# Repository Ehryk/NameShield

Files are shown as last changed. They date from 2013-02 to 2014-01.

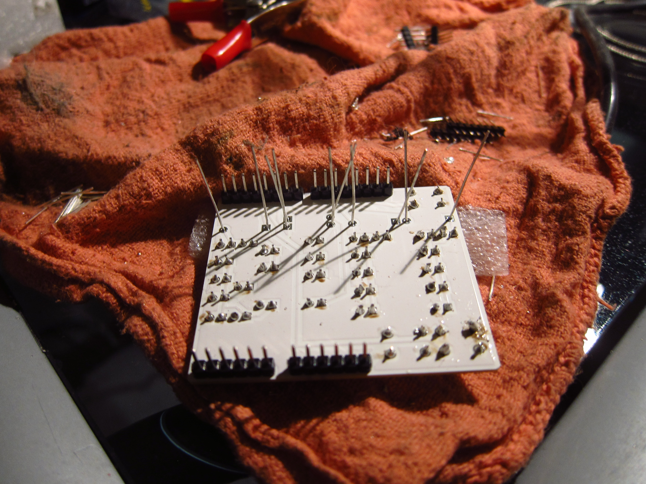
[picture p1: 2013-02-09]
Documentation/Pictures/4 - Soldering Bill.jpg

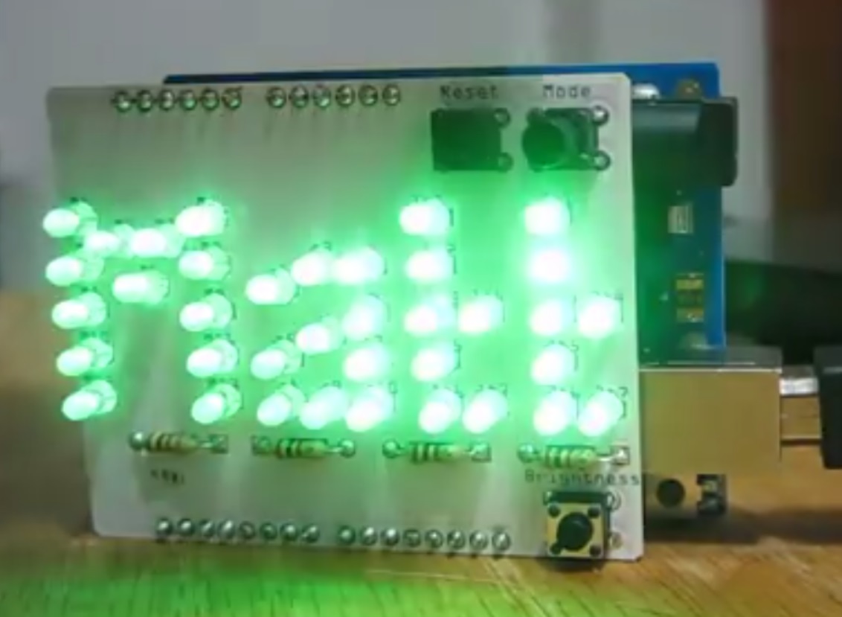
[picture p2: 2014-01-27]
Documentation/Pictures/8 - Matt LEDs On.jpg

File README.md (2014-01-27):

NameShield
==========

This is an Arduino based project that flashes text or a name on a shield, with various modes and brightnesses selectable via tact switches. It uses PWM output pins (six on an Arduino Uno/Duemilanove) to control brightness levels when necessary. I designed the circuit boards in Fritzing, then ordered them from their fabrication plant, and soldered the LEDs on.

Eric LEDs On

See the assembled ones on YouTube in various modes:
 - Eric [View on YouTube](https://www.youtube.com/watch?v=vqsRCEPevEo)
 - Bill [View on YouTube](https://www.youtube.com/watch?v=BqNwpaYB2X8)
 - Matt [View on YouTube](https://www.youtube.com/watch?v=KLYUQCO8-6A)

**Code**

These are the code files that drive the Name shields with LEDs.

Current Modes (you can easily write your own, be sure to customize them in the Modes.ino file):

 1. All On
 1. Blink All (at once)
 1. Blink All (at once) - Fast
 1. Sequential
 1. Sequential - Fast
 1. Wave
 1. Wave - Fast
 1. Blink Dot of i (if applicable)
 1. Blink First Letter
 1. Blink Second Letter
 1. Blink Third Letter
 1. Blink Fourth Letter (if applicable)
 1. Fade All
 1. Fade All - Fast
 1. Fade All - Slow
 1. All Bright
 1. All Off

**Schematics**

These are Fritzing .fzz files that define PCB schematics that can be ordered as Arduino shields. Visit [Fritzing](http://www.fritzing.org) for more information.

**Implementations**

Currently, I have built `Eric`, `Matt`, `Bill`, and `RDI`. If you'd like me to make one for you, [Email Me](mailto:ehryk42@gmail.com) or download fritzing and the Arduino IDE and build your own!

Here are some of the other variants:

Bill LEDs On
Matt LEDs On
RDI LEDs On

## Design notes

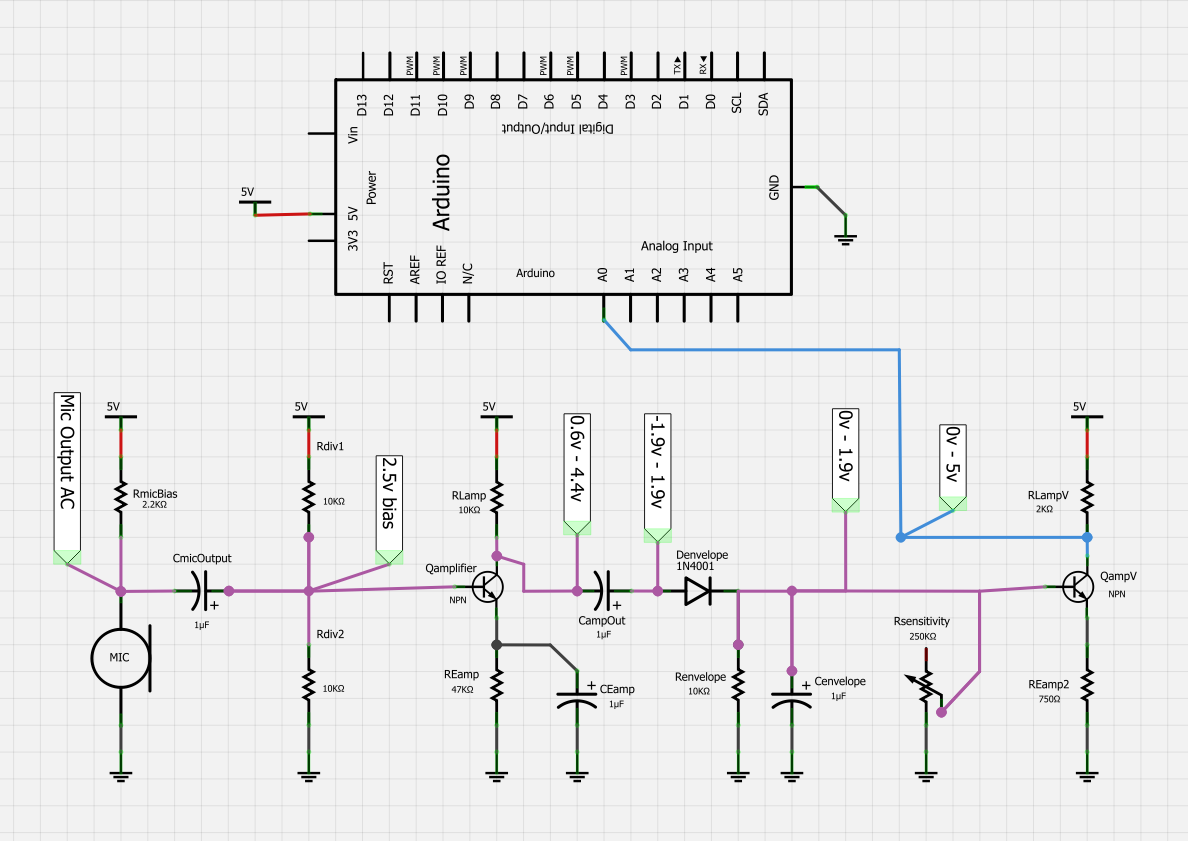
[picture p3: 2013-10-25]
Documentation/Pictures/Circuit/Electret Microphone - Complex.png

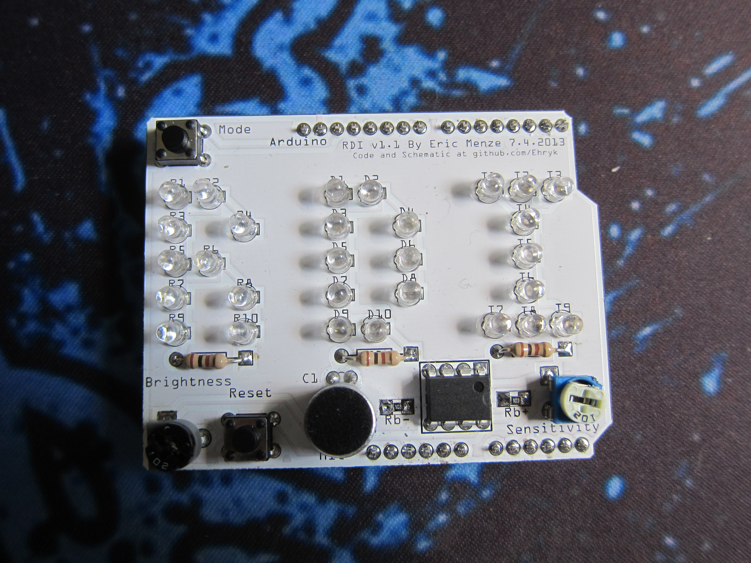
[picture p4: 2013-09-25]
Documentation/Pictures/RDI 3 - Populated Front.jpg

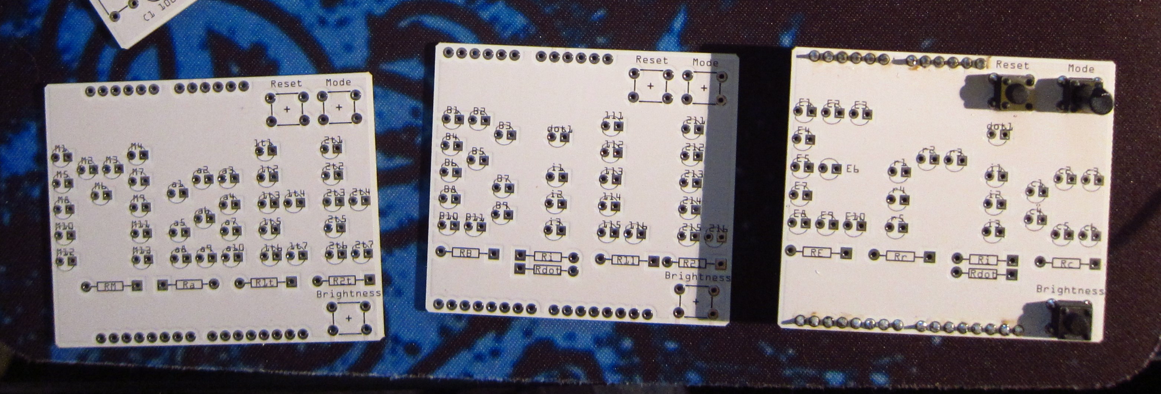
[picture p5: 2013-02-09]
Documentation/Pictures/2 - Matt, Bill, Eric PCBs.jpg

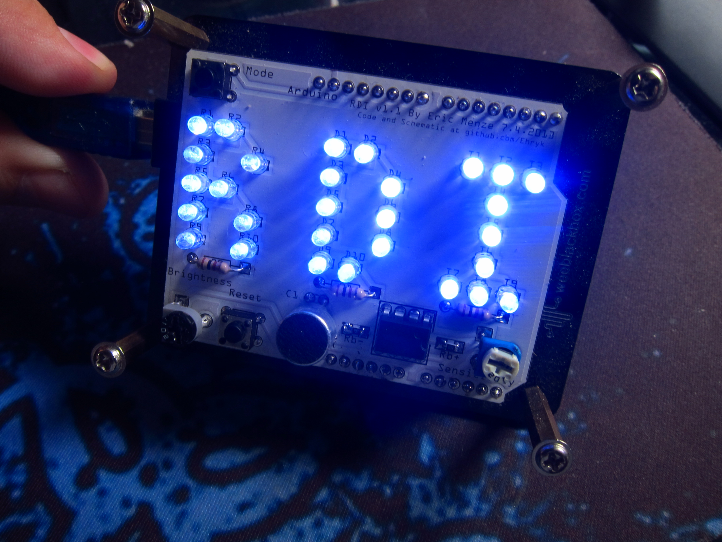
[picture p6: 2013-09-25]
Documentation/Pictures/RDI 6 - Angled.jpg

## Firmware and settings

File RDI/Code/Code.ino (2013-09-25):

/*
NameShield LED Driver
Eric Menze
http://www.github.com/Ehryk
*/

//Configure Letters
/* RDI */
int letters = 3;
char* letter[3] = {"R", "D", "I"};
int pinCount[3] = {1, 1, 1};
int letterPin[3][1] = {{11}, {10}, {9}};
int modePin = 13;
int brightnessPin = 14;
int micPin = 15;
int ledPin = 12;

int mode = 0;
int brightness = 100;
unsigned long modeTime;

boolean debug = true;
unsigned long lastDebugOutput = 0;
unsigned long debugInterval = 900;

void setup() {
  // initialize serial communication at 9600 bits per second:
  Serial.begin(9600);
  
  //Initialize letter pins to outputs
  for(int l = 0; l < letters; l++) {
    for(int p = 0; p < pinCount[l]; p++) {
      pinMode(letterPin[l][p], OUTPUT);
    }
  }
  
  pinMode(modePin, INPUT); //Set to an input to read switch status
  digitalWrite(modePin, HIGH); //Use internal pull-up resistor
  //pinMode(brightnessPin, INPUT); //Set to an input to read switch status
  //digitalWrite(brightnessPin, HIGH); //Use internal pull-up resistor
  
  //pinMode(ledPin, OUTPUT); //Set to an output to use internal LED
  //digitalWrite(ledPin, HIGH); //Turn it on
}

void loop() {
  handleInput();
  brightness = getBrightness(brightnessPin);
  
  modeTime = doMode(mode);
  
  if (debug && millis() - lastDebugOutput > debugInterval) debugWrite();
  digitalWrite(ledPin, !digitalRead(ledPin));
}

void debugWrite() {
  Serial.print("Mode: ");
  Serial.print(mode);
  Serial.print(" (");
  Serial.print(modeTime);
  Serial.println("ms)");
  
  Serial.print("Brightness: ");
  Serial.println(brightness);
  
  Serial.print("Vcc: ");
  Serial.print(readVcc());
  Serial.println("mV");
  
  Serial.println();
  
  lastDebugOutput = millis();
}

long readVcc() {
  long result;
  // Read 1.1V reference against AVcc
  ADMUX = _BV(REFS0) | _BV(MUX3) | _BV(MUX2) | _BV(MUX1);
  delay(2); // Wait for Vref to settle
  ADCSRA |= _BV(ADSC); // Convert
  while (bit_is_set(ADCSRA,ADSC));
  result = ADCL;
  result |= ADCH<<8;
  result = 1108000L / result; // Back-calculate AVcc in mV
  return result;
}

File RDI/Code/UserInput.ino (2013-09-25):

const float e = 2.71828;

boolean handleInput() {
  boolean buttonPressed = false;
  
  if (checkPress(modePin)) {
    mode++;
    if (mode > MODE_OFF) mode = 0;
    
    //Wait for release
    while(digitalRead(modePin) == LOW) { allOff(); }
    
    delay(100);
    buttonPressed = true;
  }
  
  return buttonPressed;
}

//This now uses a Logistic Function (S-Curve): https://en.wikipedia.org/wiki/Logistic_function
//This is to map the linear curve from the potentiometer to the apparent brightness from the PWMed LEDs to the human eye
//At the low end, small changes in input map to large changes in apparent brightness
//At the high end, small changes in PWM are better to avoid spikey apparent brightness
//Standard Logistic Function: f(x) = 1/(1+pow(e, -x));
//I stretch, shift, and flip it about the Y axis (so that the potentiometer rotates clockwise for 'up')
//More reading: http://electronics.stackexchange.com/questions/1983/correcting-for-non-linear-brightness-in-leds-when-using-pwm
int getBrightness(int pin) {
  float curveStretch = 100; //Lower values = faster ramp up, higher values = slower ramp up
  float curveShift = 400; //511 would center the curve, 400 favors more variance in the low end
  int linear = analogRead(pin); //Linear variance, 0-1023
  //return round(pow(2,((linear/4+1)/32))-1); //Close, but chunky (lost resolution)
  //return (((1<<(linear/4/32))-1) + ((1<<(linear/4/32))*(((linear/4)%32)+1)+15)/32); //Better... (lost resolution)
  float logistic = 1/(1+pow(e, (linear-curveShift)/curveStretch));
  return logistic * 255;
}

int getLoudness(int pin) {
  return analogRead(pin)/4;
}

//Checks if a button is pressed
boolean checkPress(int pin) {
  return digitalRead(pin) == LOW && debounce(pin, LOW, 20, 6);
}

//Software Debounce of a swtich
boolean debounce(int pin, int v, int timeDelay, int bounceCount) {
  int toCheck = bounceCount;
  while (toCheck > 0) {
    delay(timeDelay);
    if (digitalRead(pin) != v) return false;
    toCheck --;
  }
  return true;
}

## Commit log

2013-02-09 Added 'Eric' schematic
    [Eric.fzz]
2013-02-09 Added 'Bill' schematic
    [Bill.fzz]
2013-02-09 Added 'Matt' schematic
    [Matt.fzz]
2013-02-09 Organizing into Name Subdirectories, preparing to make a library
    [Bill.fzz, Eric.fzz, Matt.fzz]
2013-02-11 Updating Eric shield
    Using Arduino PCB Board
    Reverses Arduino Orientation
    Adding Transistors
    [Eric.fzz]
2013-02-11 Working on Eric: spreading name out
    [Eric.fzz]
2013-02-11 Updated Eric; Added MC14490 Debounce IC
    [Eric.fzz]
2013-02-17 Turning off between modes
    [Eric.fzz]
2013-07-04 Added RDI Shield
    [RDI.fzz]
2013-07-04 Updated RDI Schematic to 1.1
    Finished routing, added copper fill
    [RDI.fzz]
2013-07-04 Routed some disconnected grounds
    [RDI.fzz]
2013-07-26 Updating code to work with RDI NameShield
    Updated pin values
    Brightness now set by potentiometer
    Added Logistic function to map linearity of pot to apparent brightness as seen by the human eye of PWM LEDs
2013-09-25 RDI Shield - Code Update
    Added micPin, comments and fixed line endings
    [Code.ino, UserInput.ino]
